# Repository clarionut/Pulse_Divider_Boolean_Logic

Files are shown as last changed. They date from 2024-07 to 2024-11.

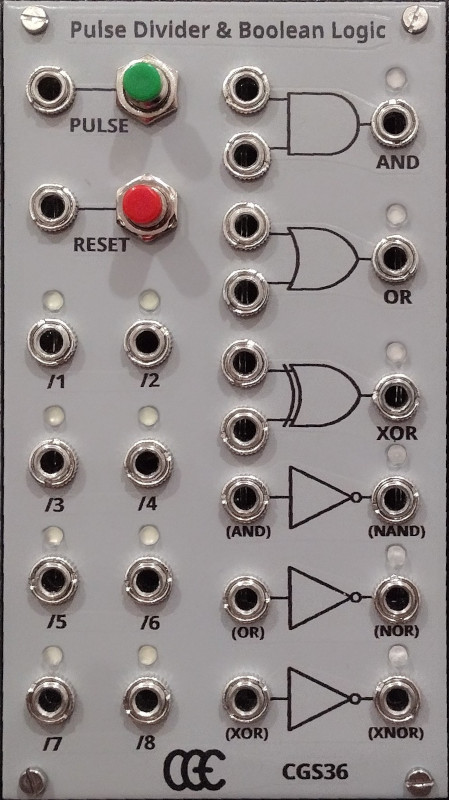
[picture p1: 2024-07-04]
PulseDiv.jpg

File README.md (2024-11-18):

# Pulse Divider and Boolean Logic

A synthesizer module based on the [original CGS36 circuit](https://sdiy.info/wiki/CGS_pulse_divider_and_Boolean_logic).

I was particularly concerned about high current consumption as the original outputs put 15V across a potential divider with a total resistance of 2.8k.
Even at Eurorack levels of 12V that's over 4mA per 'on' output, not counting the LEDs. Instead I powered the outputs from a dedicated 78L09 9V supply
(I like strong gate/trigger signals) and removed the resistor chain to ground.

The pulse divider now has a /1 output, which is a buffered copy of the incoming clock at the same voltage level as the divided outputs.

There are significant changes to the logic gates too
- the AND and OR gates have the same modification to their outputs as the pulse divider stages
- the original XOR gate can only compare signals of approximately the same voltage. This version has a voltage conditioner on its inputs (using op-amp comparators), allowing a wider range of input signals to be processed.
- the XOR comparator / output stage is an LM324 running on +9V
- the dedicated XNOR circuitry has been removed
- the NOT gates are replaced by 3 op-amp inverters using the remaining stages of the LM324. These are normalled to the AND, OR and XOR outputs providing NAND, NOR and XNOR functions by default, but can be used to invert any other logic signal for maximum flexibility

For reasons of economy I built the pulse divider and Boolean logic circuits on two separate PCBs. The logic board is daisy-chained from the divider board for its power supply, and also uses two stages of the TL084 as its input voltage conditioner. To build this board as a stand-alone unit will require a redesign with power input circuitry and a TL082 as the voltage conditioner.

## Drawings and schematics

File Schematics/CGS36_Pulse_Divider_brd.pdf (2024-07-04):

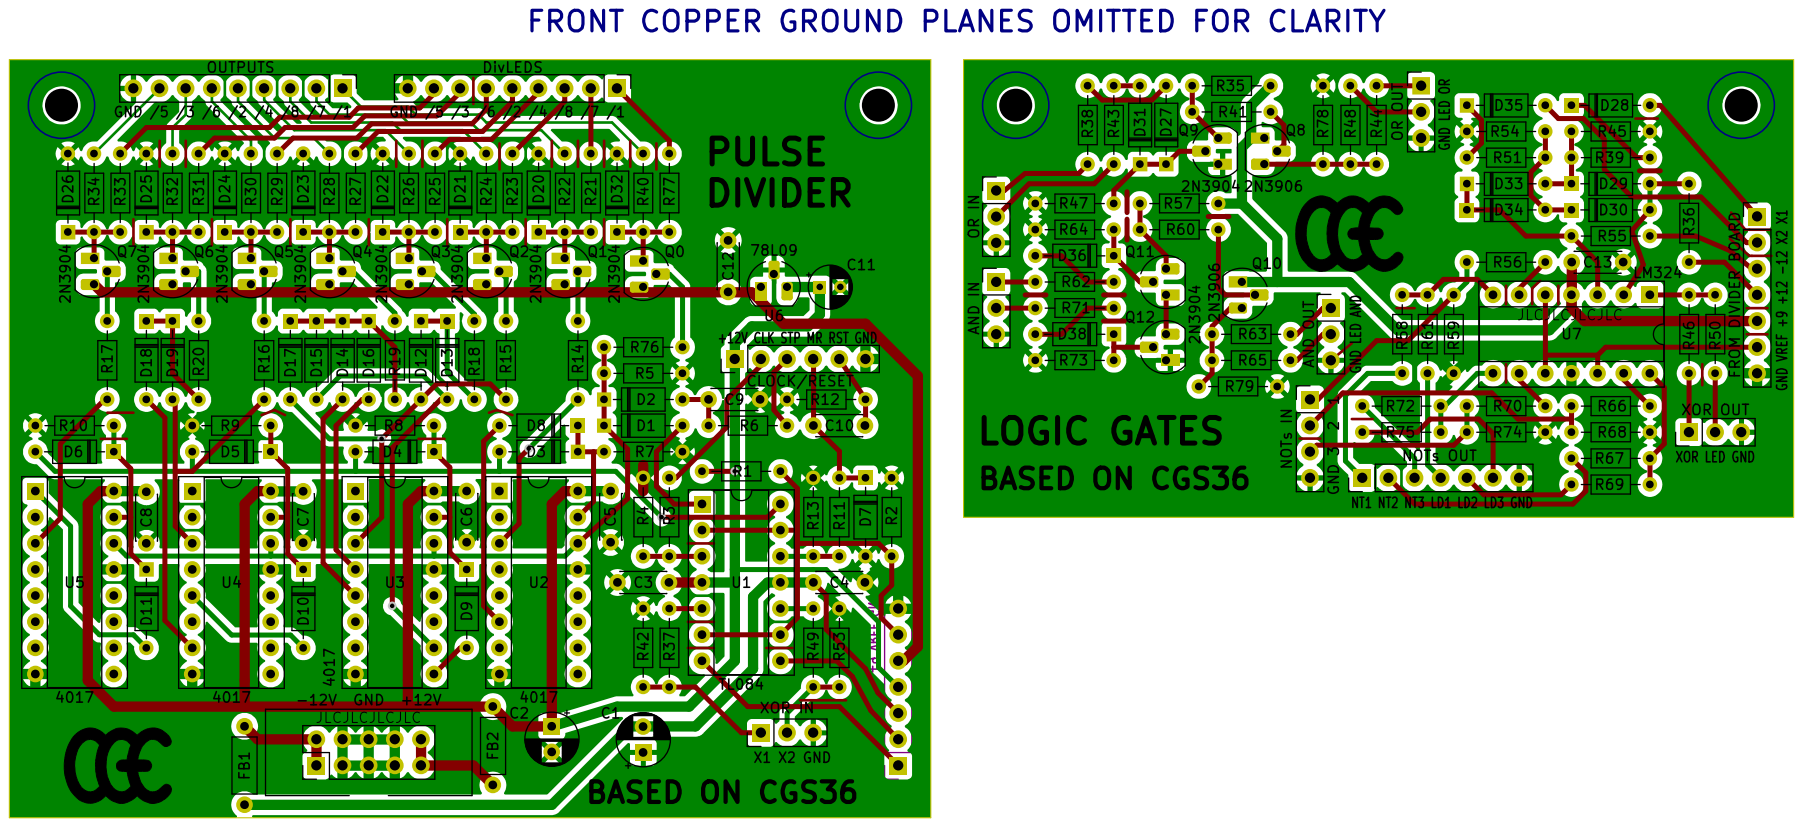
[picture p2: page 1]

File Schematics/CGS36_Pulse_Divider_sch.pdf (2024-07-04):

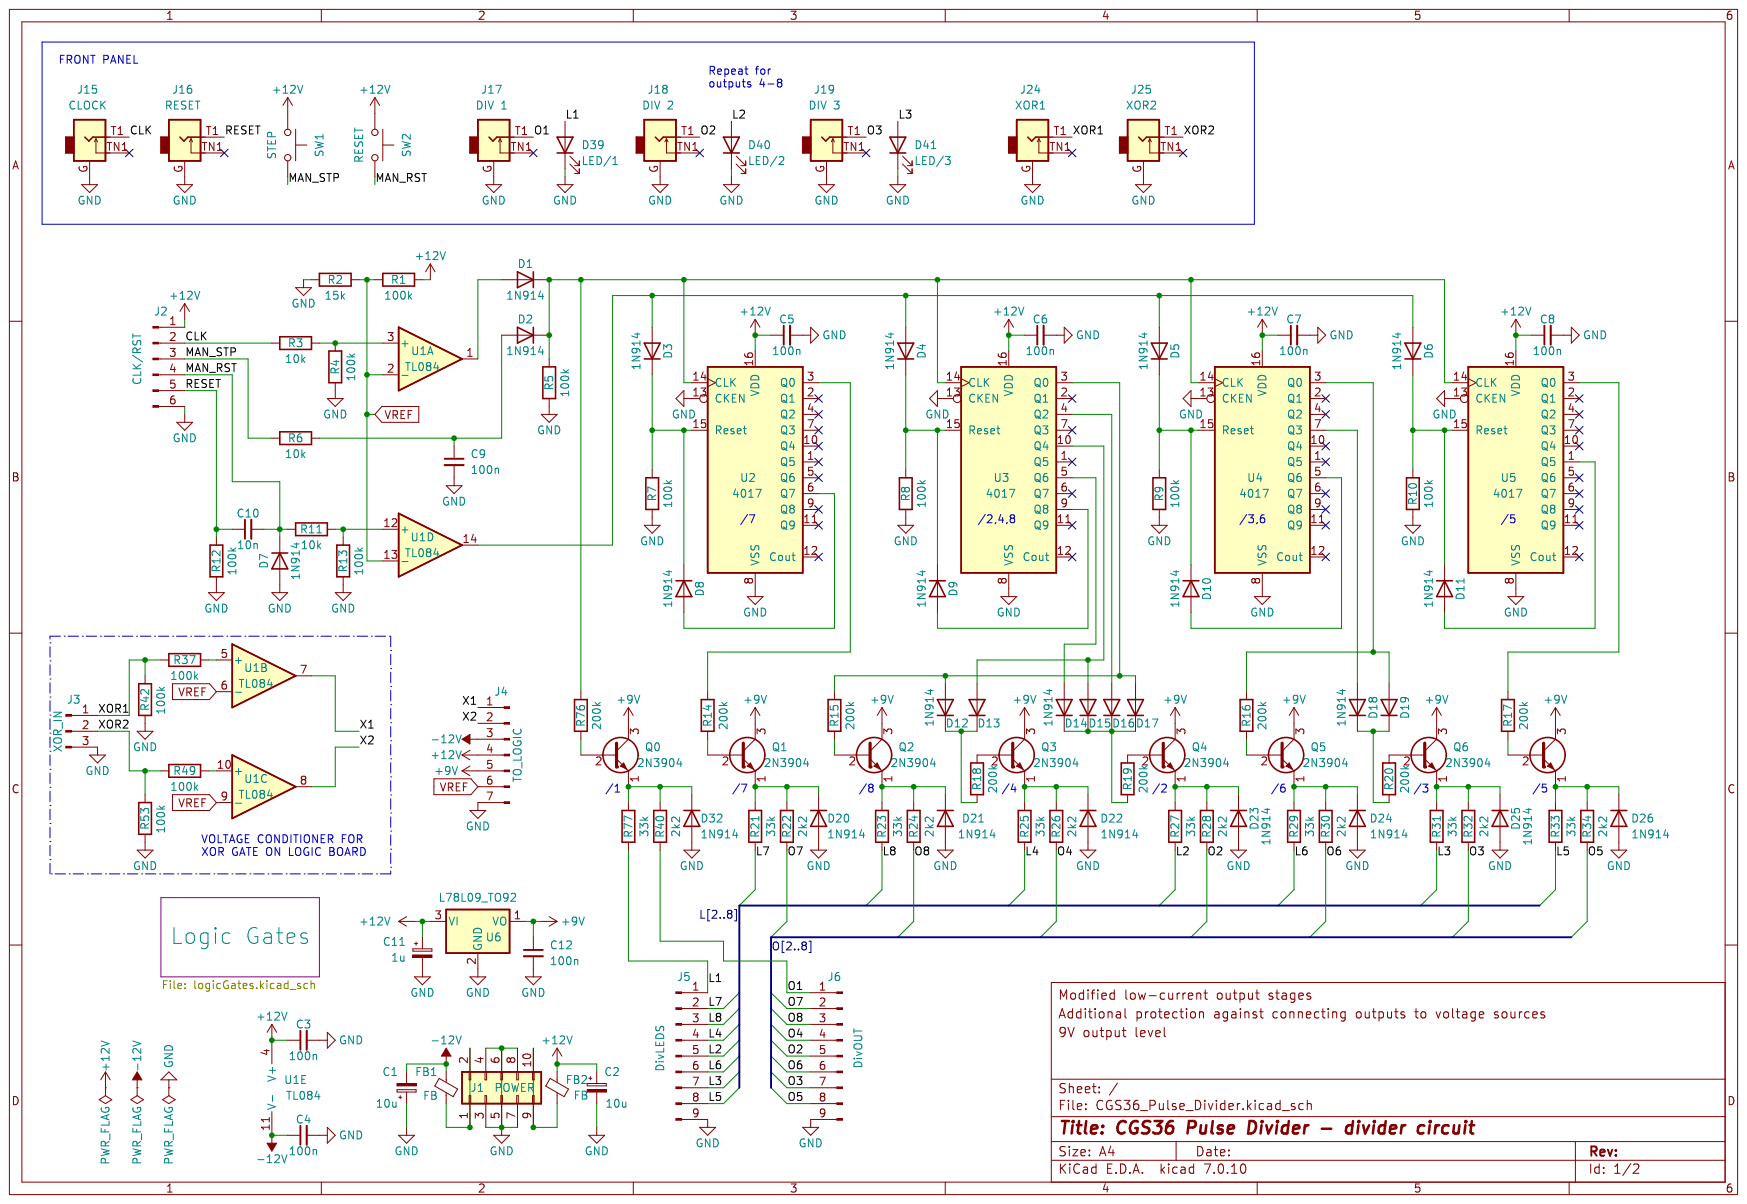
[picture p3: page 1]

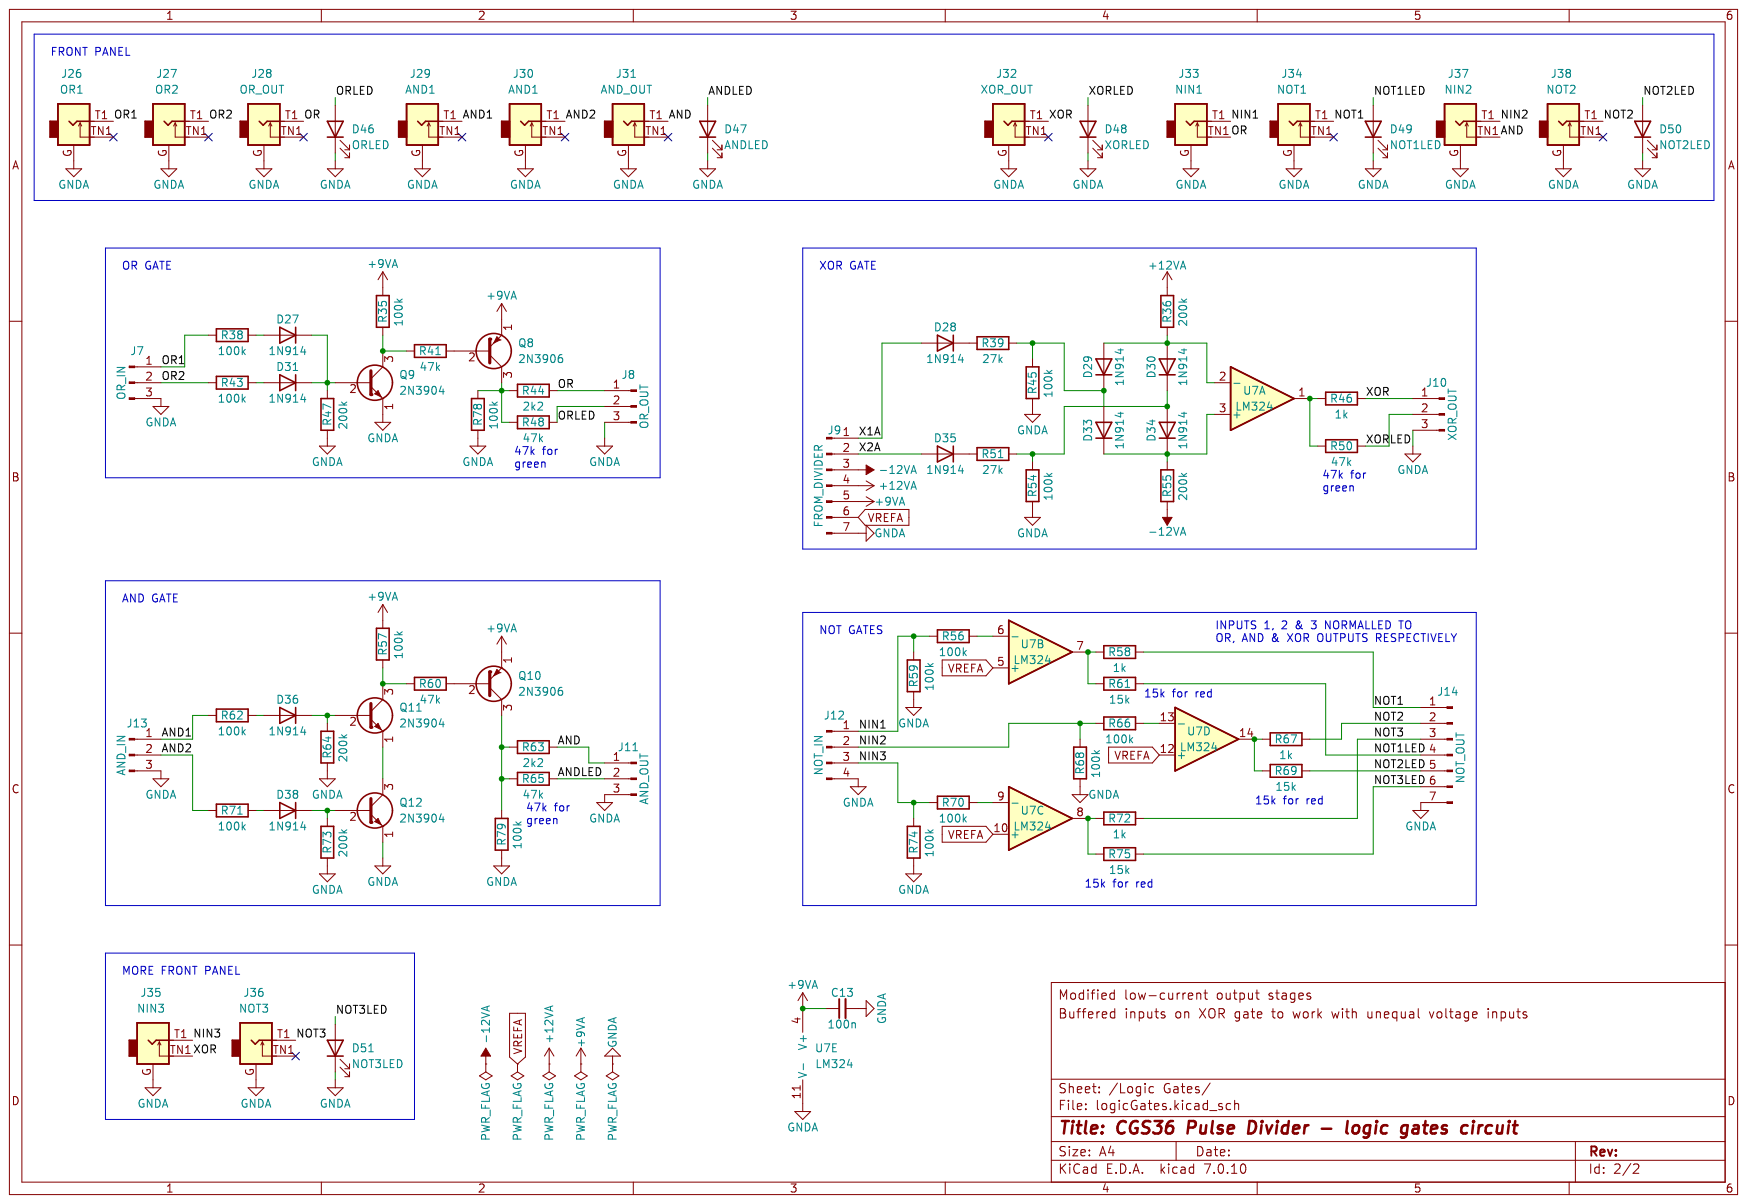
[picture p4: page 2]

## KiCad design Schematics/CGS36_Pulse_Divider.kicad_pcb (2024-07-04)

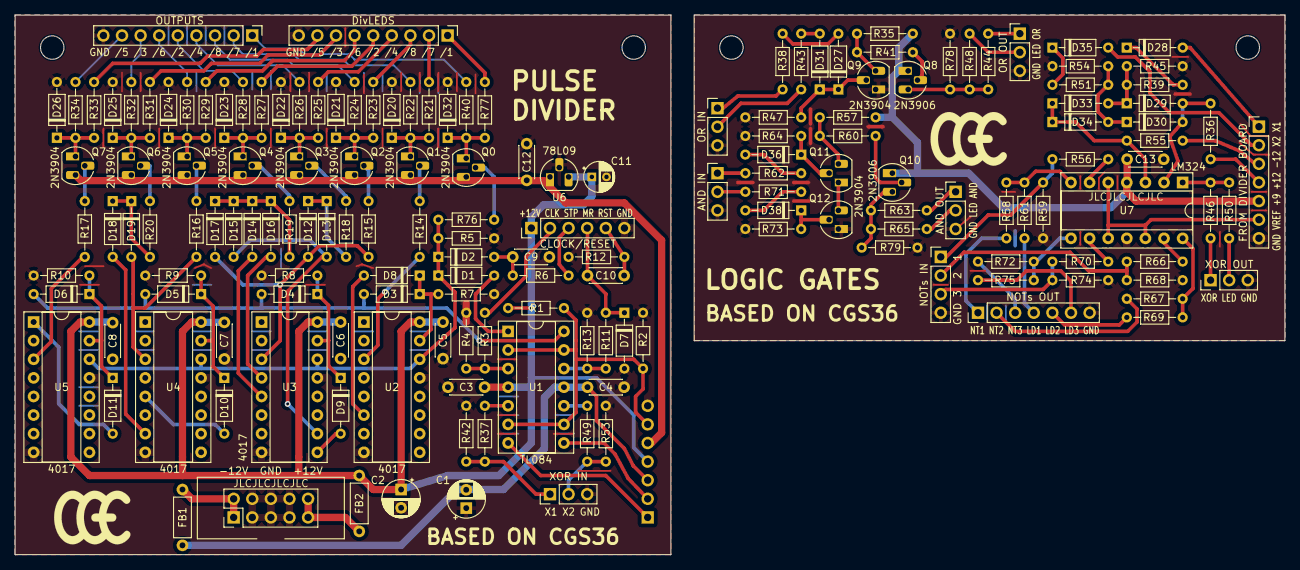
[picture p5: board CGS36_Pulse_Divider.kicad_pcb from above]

Board: 2 copper layers, 173.4 x 73.7 mm, 164 parts (1 on the bottom side), 127 nets.

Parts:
C1, C2: 10u; CP_Radial_D5.0mm_P2.50mm
C3, C4, C5, C6, C7, C8, C9, C12, C13: 100n; C_Disc_D4.3mm_W1.9mm_P5.00mm
C10: 10n; C_Disc_D4.3mm_W1.9mm_P5.00mm
C11: 1u; CP_Radial_D4.0mm_P2.00mm
D1, D2, D3, D4, D5, D6, D7, D8, D9, D10, D11, D12, D13, D14, D15, D16, D17, D18, D19, D20, D21, D22, D23, D24, D25, D26, D27, D28, D29, D30, D31, D32, D33, D34, D35, D36, D38: 1N914; D_DO-35_SOD27_P7.62mm_Horizontal
FB1, FB2: FB; L_Axial_L5.3mm_D2.2mm_P7.62mm_Horizontal_Vishay_IM-1
J1: POWER; Power_2x05
J2: CLK/RST; PinHeader_1x06_P2.54mm_Vertical
J3: XOR_IN; PinHeader_1x03_P2.54mm_Vertical
J4: TO_LOGIC; PinHeader_1x07_P2.54mm_Vertical
J5: DivLEDS; PinHeader_1x09_P2.54mm_Vertical
J6: DivOUT; PinHeader_1x09_P2.54mm_Vertical
J7: OR_IN; PinHeader_1x03_P2.54mm_Vertical
J8: OR_OUT; PinHeader_1x03_P2.54mm_Vertical
J9: FROM_DIVIDER; PinHeader_1x07_P2.54mm_Vertical
J10: XOR_OUT; PinHeader_1x03_P2.54mm_Vertical
J11: AND_OUT; PinHeader_1x03_P2.54mm_Vertical
J12: NOT_IN; PinHeader_1x04_P2.54mm_Vertical
J13: AND_IN; PinHeader_1x03_P2.54mm_Vertical
J14: NOT_OUT; PinHeader_1x07_P2.54mm_Vertical
Q0, Q1, Q2, Q3, Q4, Q5, Q6, Q7, Q9, Q11, Q12: 2N3904; TO-92_HandSolder
Q8, Q10: 2N3906; TO-92_HandSolder
R1, R4, R5, R7, R8, R9, R10, R12, R13, R35, R37, R38, R42, R43, R45, R49, R53, R54, R56, R57, R59, R62, R66, R68, R70, R71, R74, R78, R79: 100k; R_Axial_DIN0204_L3.6mm_D1.6mm_P7.62mm_Horizontal
R2, R61, R69, R75: 15k; R_Axial_DIN0204_L3.6mm_D1.6mm_P7.62mm_Horizontal
R3, R6, R11: 10k; R_Axial_DIN0204_L3.6mm_D1.6mm_P7.62mm_Horizontal
R14, R15, R16, R17, R18, R19, R20, R36, R47, R55, R64, R73, R76: 200k; R_Axial_DIN0204_L3.6mm_D1.6mm_P7.62mm_Horizontal
R21, R23, R25, R27, R29, R31, R33, R77: 33k; R_Axial_DIN0204_L3.6mm_D1.6mm_P7.62mm_Horizontal
R22, R24, R26, R28, R30, R32, R34, R40, R44, R63: 2k2; R_Axial_DIN0204_L3.6mm_D1.6mm_P7.62mm_Horizontal
R39, R51: 27k; R_Axial_DIN0204_L3.6mm_D1.6mm_P7.62mm_Horizontal
R41, R48, R50, R60, R65: 47k; R_Axial_DIN0204_L3.6mm_D1.6mm_P7.62mm_Horizontal
R46, R58, R67, R72: 1k; R_Axial_DIN0204_L3.6mm_D1.6mm_P7.62mm_Horizontal
U1: TL084; DIP-14_W7.62mm_Socket
U2, U3, U4, U5: 4017; DIP-16_W7.62mm_Socket
U6: L78L09_TO92; TO-92_HandSolder
U7: LM324; DIP-14_W7.62mm_Socket

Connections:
+9V: C12.1, J4.5, Q0.3 (C), Q1.3 (C), Q2.3 (C), Q3.3 (C), Q4.3 (C), Q5.3 (C), Q6.3 (C), Q7.3 (C), U6.1 (VO)
+9VA: C13.1, J9.5, Q8.1 (E), Q10.1 (E), R35.2, R57.2, U7.4 (V+)
+12V: C2.1, C3.1, C5.1, C6.1, C7.1, C8.1, C11.1, FB2.1, J2.1, J4.4, R1.2, U1.4 (V+), U2.16 (VDD), U3.16 (VDD), U4.16 (VDD), U5.16 (VDD), U6.3 (VI)
+12VA: J9.4, R36.2
-12V: C1.2, C4.1, FB1.1, J4.3, U1.11 (V-)
-12VA: J9.3, R55.1
/CLK: J2.2, R3.1
/L1: J5.1, R77.1
/L2: J5.5, R27.1
/L3: J5.7, R31.1
/L4: J5.4, R25.1
/L5: J5.8, R33.1
/L6: J5.6, R29.1
/L7: J5.2, R21.1
/L8: J5.3, R23.1
/Logic Gates/AND: J11.1, R63.1
/Logic Gates/AND1: J13.1, R62.2
/Logic Gates/AND2: J13.2, R71.2
/Logic Gates/ANDLED: J11.2, R65.1
/Logic Gates/NIN1: J12.1, R56.2, R59.2
/Logic Gates/NIN2: J12.2, R66.2, R68.2
/Logic Gates/NIN3: J12.3, R70.2, R74.2
/Logic Gates/NOT1: J14.1, R58.1
/Logic Gates/NOT1LED: J14.4, R61.1
/Logic Gates/NOT2: J14.2, R67.1
/Logic Gates/NOT2LED: J14.5, R69.1
/Logic Gates/NOT3: J14.3, R72.1
/Logic Gates/NOT3LED: J14.6, R75.1
/Logic Gates/OR: J8.1, R44.1
/Logic Gates/OR1: J7.1, R38.2
/Logic Gates/OR2: J7.2, R43.2
/Logic Gates/ORLED: J8.2, R48.1
/Logic Gates/X1A: D28.2 (A), J9.1
/Logic Gates/X2A: D35.2 (A), J9.2
/Logic Gates/XOR: J10.1, R46.1
/Logic Gates/XORLED: J10.2, R50.1
/MAN_RST: C10.2, D7.1 (K), J2.4, R11.1
/MAN_STP: J2.3, R6.1
/O1: J6.1, R40.1
/O2: J6.5, R28.1
/O3: J6.7, R32.1
/O4: J6.4, R26.1
/O5: J6.8, R34.1
/O6: J6.6, R30.1
/O7: J6.2, R22.1
/O8: J6.3, R24.1
/RESET: C10.1, J2.5, R12.2
/X1: J4.1, U1.7
/X2: J4.2, U1.8
/XOR1: J3.1, R37.2, R42.2
/XOR2: J3.2, R49.2, R53.2
GND: C1.1, C2.2, C3.2, C4.2, C5.2, C6.2, C7.2, C8.2, C9.2, C11.2, C12.2, D7.2 (A), D20.2 (A), D21.2 (A), D22.2 (A), D23.2 (A), D24.2 (A), D25.2 (A), D26.2 (A), D32.2 (A), J1.3, J1.4, J1.5, J1.6, J1.7, J1.8, J2.6, J3.3, J4.7, J5.9, J6.9, R2.1, R4.1, R5.1, R7.1, R8.1, R9.1, R10.1, R12.1, R13.1, R42.1, R53.1, U2.8 (VSS), U2.13 (CKEN), U3.8 (VSS), U3.13 (CKEN), U4.8 (VSS), U4.13 (CKEN), U5.8 (VSS), U5.13 (CKEN), U6.2 (GND)
GNDA: C13.2, J7.3, J8.3, J9.7, J10.3, J11.3, J12.4, J13.3, J14.7, Q9.1 (E), Q12.1 (E), R45.1, R47.1, R54.1, R59.1, R64.1, R68.1, R73.1, R74.1, R78.1, R79.1, U7.11 (V-)
unnamed: D1.2 (A), U1.1
unnamed: D1.1 (K), D2.1 (K), R5.2, R76.2, U2.14 (CLK), U3.14 (CLK), U4.14 (CLK), U5.14 (CLK)
unnamed: C9.1, D2.2 (A), R6.2
unnamed: D3.2 (A), D4.2 (A), D5.2 (A), D6.2 (A), U1.14
unnamed: D3.1 (K), D8.1 (K), R7.2, U2.15 (Reset)
unnamed: D4.1 (K), D9.1 (K), R8.2, U3.15 (Reset)
unnamed: D8.2 (A), U2.6 (Q7)
unnamed: D9.2 (A), U3.9 (Q8)
unnamed: D10.2 (A), U4.5 (Q6)
unnamed: D5.1 (K), D10.1 (K), R9.2, U4.15 (Reset)
unnamed: D11.2 (A), U5.1 (Q5)
unnamed: D6.1 (K), D11.1 (K), R10.2, U5.15 (Reset)
unnamed: D12.2 (A), D17.2 (A), R15.2, U3.3 (Q0)
unnamed: D12.1 (K), D13.1 (K), R18.1
unnamed: D13.2 (A), D15.2 (A), U3.10 (Q4)
unnamed: D14.2 (A), U3.5 (Q6)
unnamed: D14.1 (K), D15.1 (K), D16.1 (K), D17.1 (K), R19.1
unnamed: D16.2 (A), U3.4 (Q2)
unnamed: D18.2 (A), U4.7 (Q3)
unnamed: D18.1 (K), D19.1 (K), R20.1
unnamed: D19.2 (A), R16.2, U4.3 (Q0)
unnamed: D20.1 (K), Q1.1 (E), R21.2, R22.2
unnamed: D21.1 (K), Q2.1 (E), R23.2, R24.2
unnamed: D22.1 (K), Q3.1 (E), R25.2, R26.2
unnamed: D23.1 (K), Q4.1 (E), R27.2, R28.2
unnamed: D24.1 (K), Q5.1 (E), R29.2, R30.2
unnamed: D25.1 (K), Q6.1 (E), R31.2, R32.2
unnamed: D26.1 (K), Q7.1 (E), R33.2, R34.2
unnamed: D27.2 (A), R38.1
unnamed: D27.1 (K), D31.1 (K), Q9.2 (B), R47.2
unnamed: D28.1 (K), R39.2
unnamed: D29.2 (A), D30.2 (A), R36.1, U7.2 (-)
unnamed: D29.1 (K), D33.2 (A), R39.1, R45.2
unnamed: D30.1 (K), D34.2 (A), R51.1, R54.2
unnamed: D31.2 (A), R43.1
unnamed: D32.1 (K), Q0.1 (E), R40.2, R77.2
unnamed: D33.1 (K), D34.1 (K), R55.2, U7.3 (+)
unnamed: D35.1 (K), R51.2
unnamed: D36.2 (A), R62.1
unnamed: D36.1 (K), Q11.2 (B), R64.2
unnamed: D38.2 (A), R71.1
unnamed: D38.1 (K), Q12.2 (B), R73.2
unnamed: FB1.2, J1.1, J1.2
unnamed: FB2.2, J1.9, J1.10
unnamed: Q0.2 (B), R76.1
unnamed: Q1.2 (B), R14.1
unnamed: Q2.2 (B), R15.1
unnamed: Q3.2 (B), R18.2
unnamed: Q4.2 (B), R19.2
unnamed: Q5.2 (B), R16.1
unnamed: Q6.2 (B), R20.2
unnamed: Q7.2 (B), R17.1
unnamed: Q8.2 (B), R41.1
unnamed: Q8.3 (C), R44.2, R48.2, R78.2
unnamed: Q9.3 (C), R35.1, R41.2
unnamed: Q10.2 (B), R60.1
unnamed: Q10.3 (C), R63.2, R65.2, R79.2
unnamed: Q11.3 (C), R57.1, R60.2
unnamed: Q11.1 (E), Q12.3 (C)
unnamed: R46.2, R50.2, U7.1
unnamed: R58.2, R61.2, U7.7
unnamed: R67.2, R69.2, U7.14
unnamed: R72.2, R75.2, U7.8
unnamed: R3.2, R4.2, U1.3 (+)
unnamed: R37.1, U1.5 (+)
unnamed: R49.1, U1.10 (+)
unnamed: R11.2, R13.2, U1.12 (+)
unnamed: R14.2, U2.3 (Q0)
unnamed: R17.2, U5.3 (Q0)
unnamed: R56.1, U7.6 (-)
unnamed: R70.1, U7.9 (-)
unnamed: R66.1, U7.13 (-)
VREF: J4.6, R1.1, R2.2, U1.2 (-), U1.6 (-), U1.9 (-), U1.13 (-)
VREFA: J9.6, U7.5 (+), U7.10 (+), U7.12 (+)
